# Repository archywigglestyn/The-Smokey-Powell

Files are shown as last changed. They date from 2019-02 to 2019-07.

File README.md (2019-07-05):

# The-Smokey-Powell
The Particle Photon Wifi Blynk controlled BBQ Smoker controller

This controller reads temperature through a thermistor. Control of your smokers heat is made through a fan or
Solid State relay. It has three extra probe inputs to be used as meat probes.
Wifi is used to connect to the cloud. 

The blynk app is used as the main interface from your phone or mobile device. It is worth noting that all the information runs through the cloud. This means one could be shopping for supplies, while also monitoring ones bbq back at home.

A 4x20 I2c LCD is used as a local display and four buttons as the interface controls.
The local interface is a little clunky. The main interface was intended to be the blynk app.

This controller can use replacement thermistors for Weber iGrill2 grilling thermometer. Or any other thermistor that will work 
with a 10k ohm reference resistor.

For those that use the circuit board I designed. The Outputs are sinking.

Watch The Youtube video for more information.
https://youtu.be/kV1lrQCiiBc

Included are links below or look above in the files.

Version 1.2 Fixes issues with slow internet by using event based communication with blynk compaired to timed.
Also allows smoke percent to be set while in off mode.
Version 1.3, 6-16-19 Renames a variable to an unused name. so that the code will compile.

1.4, 7-4-19 A fellow creator found a variable I forgot to change.
https://go.particle.io/shared_apps/5d1ea377e9731c0017650d83

The Blynk App (Look Above) Download Blynk. In Blynk there is an option take a picture of the QR code.

The circuit board gerber file	(Look Above)  Send this Zip file in to order a board. Board dimensions are 4.75"x2.5"
I may also decide to sell them	 3-29-18 I uploaded V1.1, It has a few minor fixes.

where I have my circuit boards made http://www.pcbunlimited.com/ They are great quality and cheap!
Look for Panel Share. It moves around on the website but it's the cheapest way if you only want one. $19.95 as of 3/15/19

schematic of circuit board	SCH,PDF, and BRD (Look Above)

thingiverse link to make 3d printed cases and DIN mounts https://www.thingiverse.com/thing:3453571

Smokey Powell shopping list:

Bill of Material (Look Above)
digikey (some items are optional) you can use screw terminals or barrel jacks for power, outputs and inputs. Really you can use anything you like that matches the pitch. You could even solder wires directly.
(I have not tested all of the parts on this list yet.)

meat probes, https://www.amazon.com/Weber-iGrill-Pro-Meat-Probe/dp/B01M8LG8U5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

2n2222a or 2n2222 these are cheap and appear to be everywhere except Digikey. Looks like they are becoming obsolete. You will need three of them.	
https://www.amazon.com/2N2222-Plastic-Encapsulate-Power-Transistors-600mA/dp/B06XPWS52G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

This is the particle photon. The brains of the operation.
https://www.amazon.com/Particle-Reprogrammable-Development-Prototyping-Electronics/dp/B016YNU1A0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

Optional items:

5vdc buzzer 12mm use this if you want a microwave like beep for the alarm. Otherwise attach whatever you want to the relay, noise maker, light, spinning flag motor.
	https://www.amazon.com/gp/product/B00B0Q4KKO/ref=oh_aui_detailpage_o02_s00?ie=UTF8&psc=1

SS Relay	these work good if you are going to do some high power electric smoking
	https://www.amazon.com/gp/product/B0087ZTN08/ref=oh_aui_search_detailpage?ie=UTF8&psc=1

Antenna
Add an Antenna for extra range. Be sure to switch the text to external in the program.
	https://www.amazon.com/gp/product/B01GMBUS8O/ref=oh_aui_detailpage_o01_s00?ie=UTF8&psc=1

bbq guru Fan	
If you want to use a fan. This is an option. although it does not like pwm so you need to set the pulse range threshold to 100. Otherwise many 12vdc pc fans work well at about 30%
https://www.bbqguru.com/storenav?CategoryId=2&ProductId=44

The connectors I used for the screen
https://www.amazon.com/Hilitchi-JST-XHP-housing-Connector-Adapter/dp/B015Y6JOUG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

Dayton 3FRG5 DC Blower, 12 VDC, 57 CFM. This is a Big blower. The screen dims on my controller when it starts. works well with PWM.
https://www.amazon.com/gp/product/B004KFI6HK/ref=ppx_yo_dt_b_asin_title_o00_s00?ie=UTF8&psc=1

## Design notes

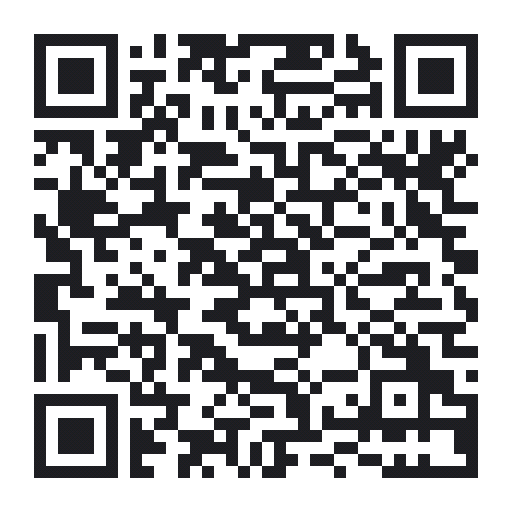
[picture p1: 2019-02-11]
Blynk App.png

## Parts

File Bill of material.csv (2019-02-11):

Manufacturer Part Number | Manufacturer | Digi-Key Part Number | Quantity | Unit Price | Extended Price | Description
MJ1-2503A | CUI Inc. | CP1-2503AM-ND | 4 | 0.71000 | $2.84 | CONN JACK MONO 2.5MM R/A
UFW1E470MDD1TD | Nichicon | 493-10997-1-ND | 2 | 0.24000 | $0.48 | CAP ALUM 47UF 20% 25V RADIAL
CF14JT100R | Stackpole Electronics Inc. | CF14JT100RCT-ND | 2 | 0.10000 | $0.20 | RES 100 OHM 1/4W 5% AXIAL
CF14JT220R | Stackpole Electronics Inc. | CF14JT220RCT-ND | 2 | 0.10000 | $0.20 | RES 220 OHM 1/4W 5% AXIAL
CF14JT470R | Stackpole Electronics Inc. | CF14JT470RCT-ND | 3 | 0.10000 | $0.30 | RES 470 OHM 1/4W 5% AXIAL
CF14JT680R | Stackpole Electronics Inc. | CF14JT680RCT-ND | 3 | 0.10000 | $0.30 | RES 680 OHM 1/4W 5% AXIAL
CF14JT4K70 | Stackpole Electronics Inc. | CF14JT4K70CT-ND | 2 | 0.10000 | $0.20 | RES 4.7K OHM 1/4W 5% AXIAL
LTV-817 | Lite-On Inc. | 160-1366-5-ND | 2 | 0.41000 | $0.82 | OPTOISOLATR 5KV TRANSISTOR 4-DIP
FQP30N06 | ON Semiconductor | FQP30N06FS-ND | 2 | 1.43000 | $2.86 | MOSFET N-CH 60V 30A TO-220
1N5819-E3/54 | Vishay Semiconductor Diodes Division | 1N5819-E3/54GICT-ND | 3 | 0.49000 | $1.47 | DIODE SCHOTTKY 40V 1A DO204AL
1825910-6 | TE Connectivity ALCOSWITCH Switches | 450-1650-ND | 4 | 0.11000 | $0.44 | SWITCH TACTILE SPST-NO 0.05A 24V
G5V-1-2 DC5 | Omron Electronics Inc-EMC Div | Z3824-ND | 1 | 2.34000 | $2.34 | RELAY GEN PURPOSE SPDT 1A 5VDC
EJ508A | MPD (Memory Protection Devices) | EJ508A-ND | 4 | 1.18000 | $4.72 | CONN PWR JACK 2.1X5.5MM SOLDER
C503B-RCN-CW0Z0AA1 | Cree Inc. | C503B-RCN-CW0Z0AA1-ND | 1 | 0.15000 | $0.15 | LED RED CLEAR 5MM ROUND T/H
C503B-GCS-CY0C0791 | Cree Inc. | C503B-GCS-CY0C0791-ND | 1 | 0.25000 | $0.25 | LED GREEN CLEAR 5MM ROUND T/H
C503B-BCN-CV0Z0461 | Cree Inc. | C503B-BCN-CV0Z0461-ND | 1 | 0.21000 | $0.21 | LED BLUE CLEAR 5MM ROUND T/H
L7805CV | STMicroelectronics | 497-1443-5-ND | 1 | 0.52000 | $0.52 | IC REG LINEAR 5V 1.5A TO220AB
507302B00000G | Aavid, Thermal Division of Boyd Corporation | HS115-ND | 1 | 0.41000 | $0.41 | HEATSINK TO-220 2.5W LOW PROFILE
4880G | Aavid, Thermal Division of Boyd Corporation | HS417-ND | 1 | 2.64000 | $2.64 | MOUNTING KIT TO-220
TR2A | Switchcraft Inc. | SC1514-ND | 1 | 3.42000 | $3.42 | CONN JACK MONO 2.46MM PNL MNT
PPTC121LFBN-RC | Sullins Connector Solutions | S6100-ND | 2 | 0.78000 | $1.56 | CONN HDR 12POS 0.1 TIN PCB
OSTVN04A150 | On Shore Technology Inc. | ED10563-ND | 4 | 1.43000 | $5.72 | TERM BLK 4P SIDE ENT 2.54MM PCB
OSTVN02A150 | On Shore Technology Inc. | ED10561-ND | 1 | 0.94000 | $0.94 | TERM BLK 2P SIDE ENT 2.54MM PCB
OSTVN05A150 | On Shore Technology Inc. | ED10564-ND | 1 | 1.80000 | $1.80 | TERM BLK 5P SIDE ENT 2.54MM PCB
ED500/2DS | On Shore Technology Inc. | ED1623-ND | 1 | 0.98000 | $0.98 | TERM BLK 2POS SIDE ENTRY 5MM PCB
OSTTC030162 | On Shore Technology Inc. | ED2601-ND | 1 | 0.95000 | $0.95 | TERM BLK 3POS SIDE ENTRY 5MM PCB
CF14JT10K0 | Stackpole Electronics Inc. | CF14JT10K0CT-ND | 6 | 0.10000 | $0.60 | RES 10K OHM 1/4W 5% AXIAL
SR205E104MAR | AVX Corporation | 478-3192-ND | 6 | 0.22000 | $1.32 | CAP CER 0.1UF 50V Z5U RADIAL

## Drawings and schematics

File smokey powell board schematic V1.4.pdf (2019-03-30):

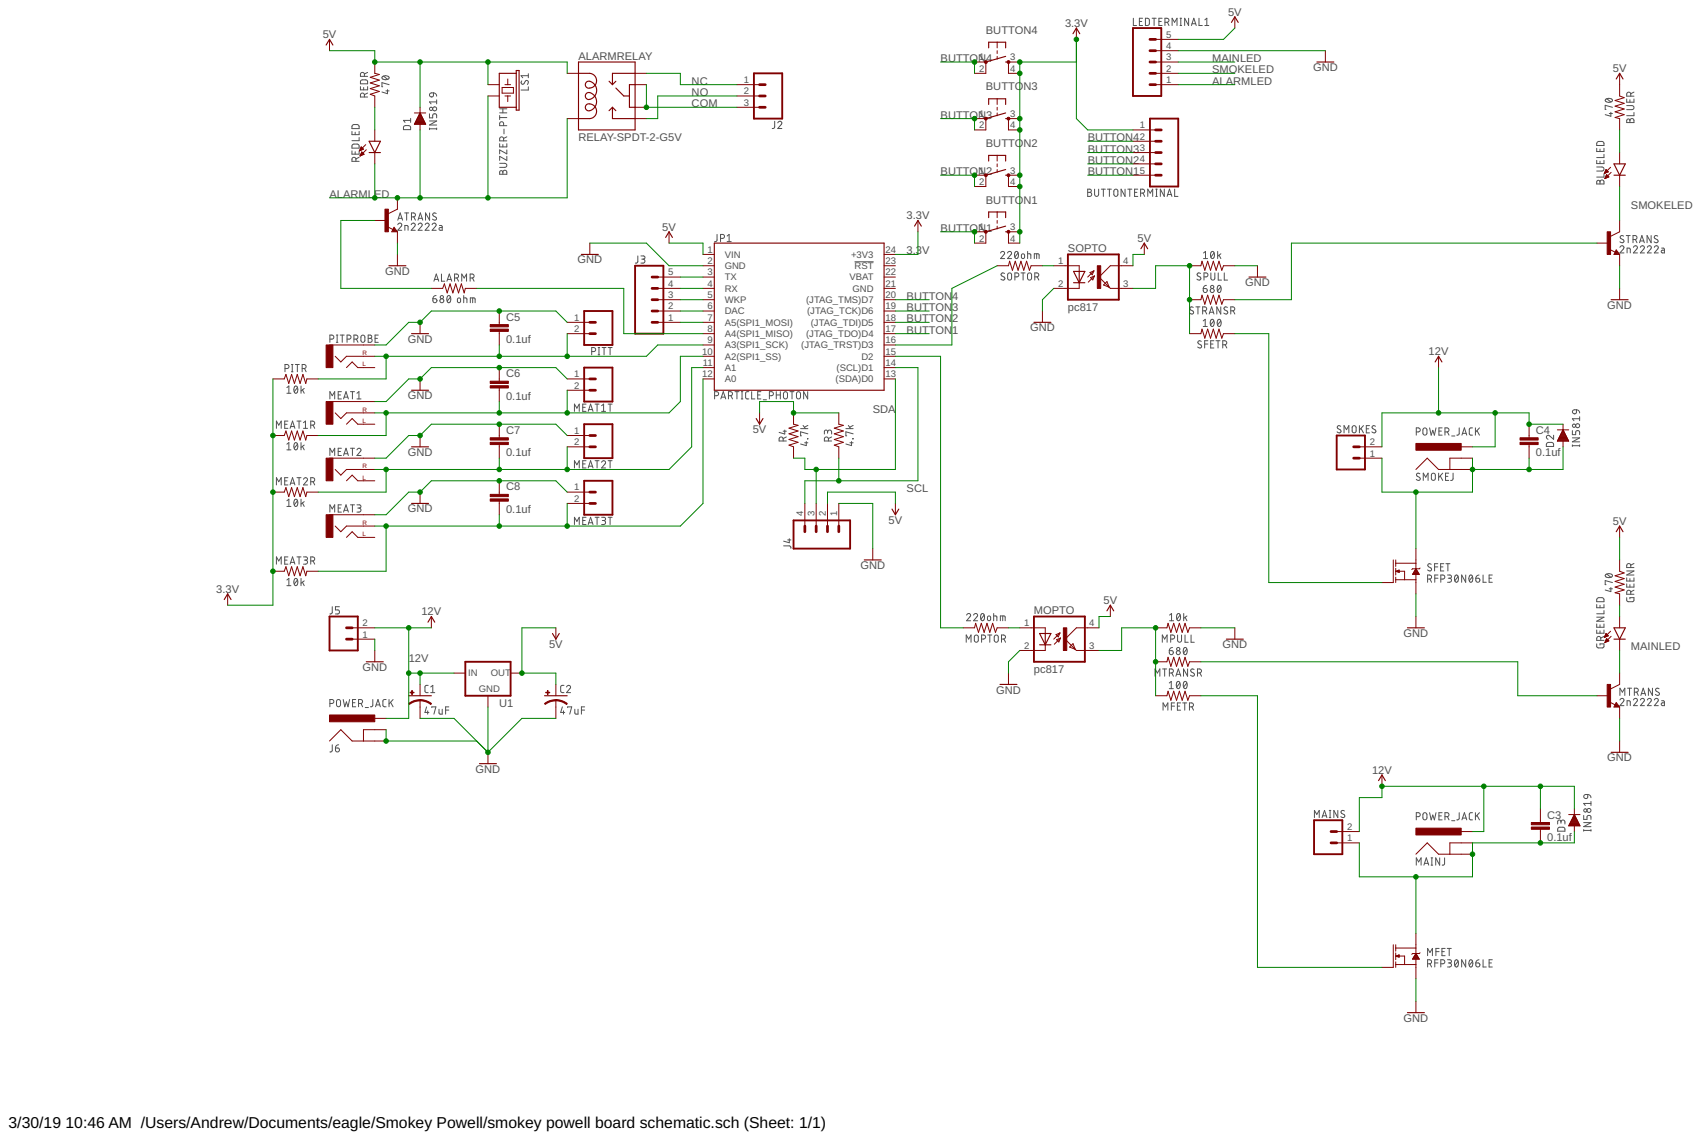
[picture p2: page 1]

3/30/19 10:46 AM /Users/Andrew/Documents/eagle/Smokey Powell/smokey powell board schematic.sch (Sheet: 1/1)

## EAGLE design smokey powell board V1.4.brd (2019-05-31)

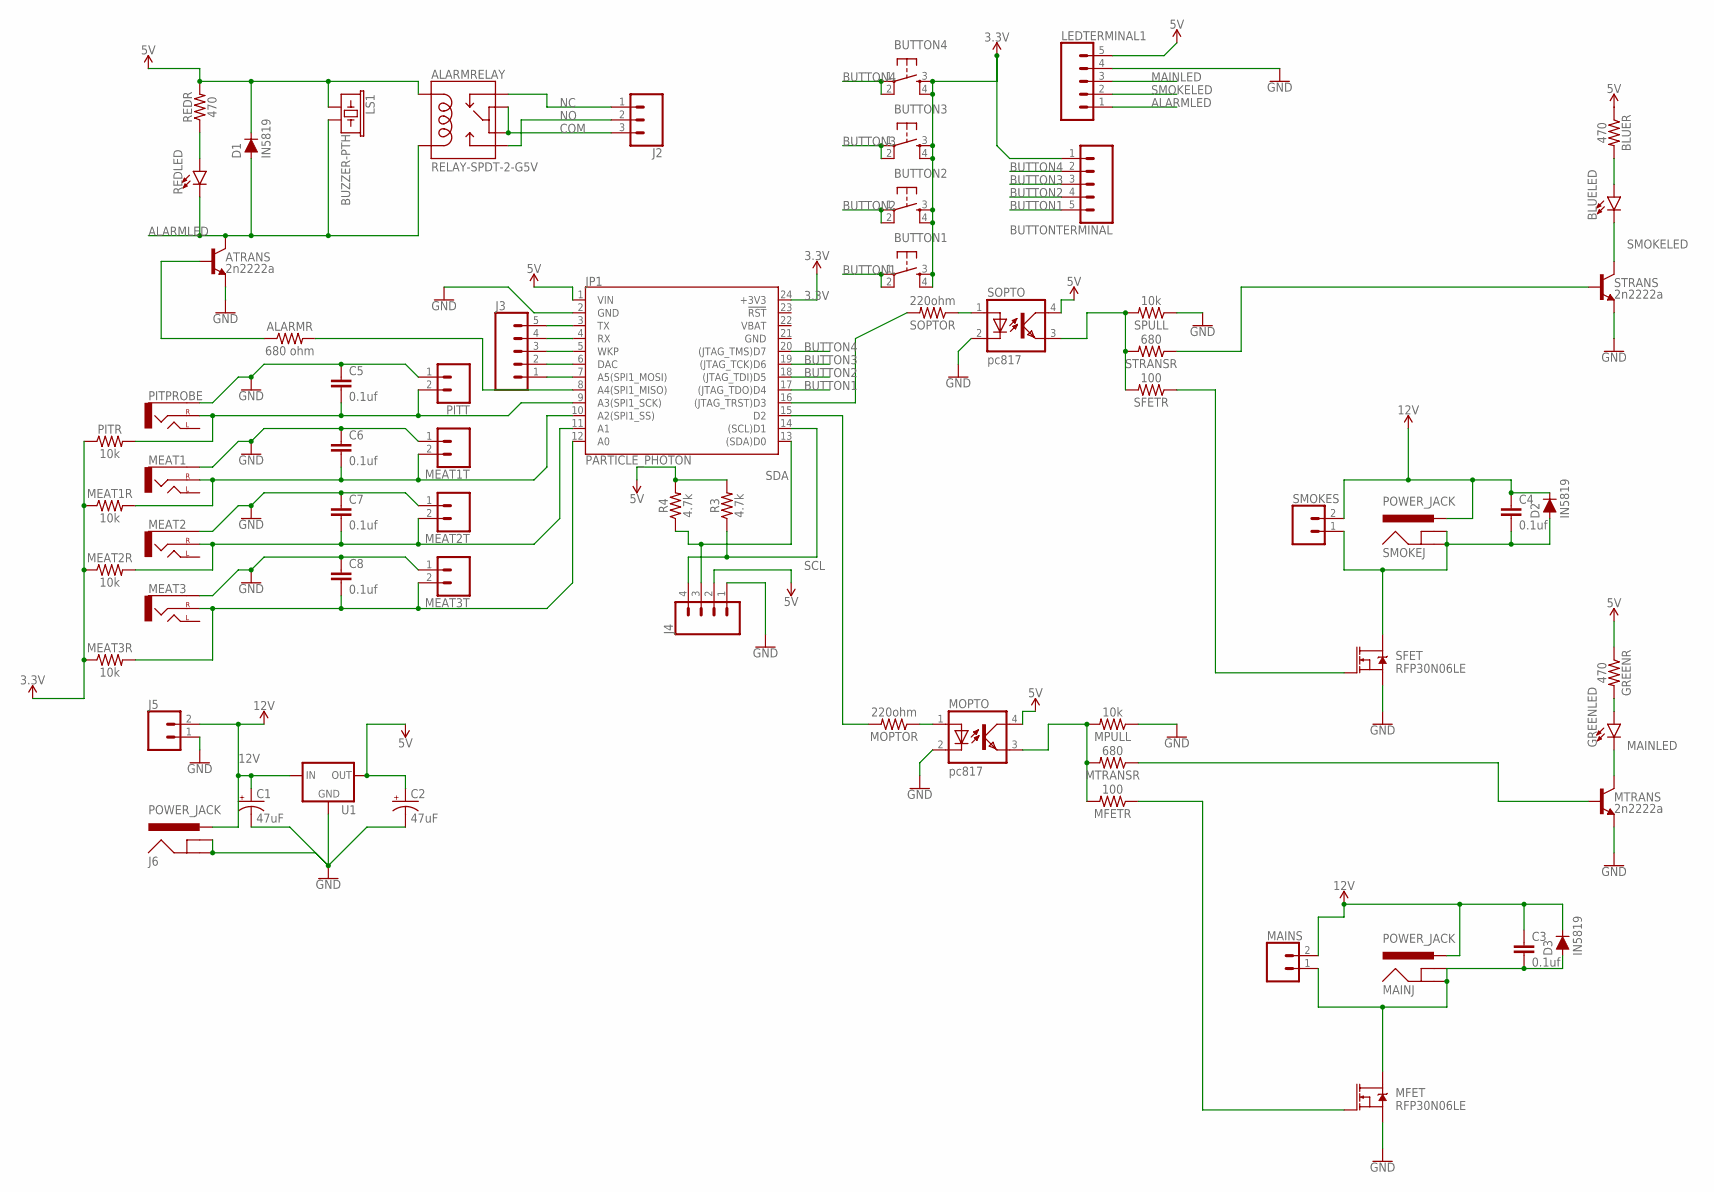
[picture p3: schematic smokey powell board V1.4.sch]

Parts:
ALARMR: 680 ohm; AXIAL-0.3
ALARMRELAY: RELAY-SPDT-2-G5V; RELAY-G5V
ATRANS: 2n2222a; TO-92
BLUELED: LED5MM; LED_5MM
BLUER: 470; AXIAL-0.3
BUTTON1, BUTTON2, BUTTON3, BUTTON4: TAC_SWITCHPTH; TACTILE-PTH
BUTTONTERMINAL: CONN_05PTH_LONGPADS; 1X05_LONGPADS
C1, C2: 47uF; CPOL-RADIAL-2.5MM-6.5MM
C3, C4, C5, C6, C7, C8: 0.1uf; C2.5-2
D1, D2, D3: IN5819; DIODE-1N4001
GREENLED: LED5MM; LED_5MM
GREENR: 470; AXIAL-0.3
J2: CONN_03-SCREW-5MM; SCREWTERMINAL-5MM-3
J3: CONN_05; 1X05
J4: CONN_04LONGPADS; 1X04_LONGPADS
J5: CONN_025MM; SCREWTERMINAL-5MM-2
J6: POWER_JACK; POWER_JACK_PTH
JP1: PARTICLE_PHOTON
LEDTERMINAL1: CONN_05PTH_LONGPADS; 1X05_LONGPADS
LS1: BUZZER-PTH; BUZZER-12MM
MAINJ: POWER_JACK; POWER_JACK_PTH
MAINS: CONN_025MM; SCREWTERMINAL-5MM-2
MEAT1, MEAT2, MEAT3: AUDIO_JACK_2.5MM_2.5MM; STEREOJACK2.5MM_STEREOJACK2.5MM
MEAT1R, MEAT2R, MEAT3R: 10k; AXIAL-0.3
MEAT1T, MEAT2T, MEAT3T: CONN_02PTH3; 1X02_LONGPADS
MFET: RFP30N06LE; TO220V
MFETR: 100; AXIAL-0.3
MOPTO: pc817; DIP4
MOPTOR: 220ohm; AXIAL-0.3
MPULL: 10k; AXIAL-0.3
MTRANS: 2n2222a; TO-92
MTRANSR: 680; AXIAL-0.3
PITPROBE: AUDIO_JACK_2.5MM_2.5MM; STEREOJACK2.5MM_STEREOJACK2.5MM
PITR: 10k; AXIAL-0.3
PITT: CONN_02PTH3; 1X02_LONGPADS
R3, R4: 4.7k; AXIAL-0.3
REDLED: LED5MM; LED_5MM
REDR: 470; AXIAL-0.3
SFET: RFP30N06LE; TO220V
SFETR: 100; AXIAL-0.3
SMOKEJ: POWER_JACK; POWER_JACK_PTH
SMOKES: CONN_025MM; SCREWTERMINAL-5MM-2
SOPTO: pc817; DIP4
SOPTOR: 220ohm; AXIAL-0.3
SPULL: 10k; AXIAL-0.3
STRANS: 2n2222a; TO-92
STRANSR: 680; AXIAL-0.3
U1: V_REG_78XXSINK; TO220-IGO

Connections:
3.3V: BUTTON1.3, BUTTON1.4, BUTTON2.3, BUTTON2.4, BUTTON3.3, BUTTON3.4, BUTTON4.3, BUTTON4.4, BUTTONTERMINAL.1, JP1.24 (+3V3), MEAT1R.P$1 (1), MEAT2R.P$1 (1), MEAT3R.P$1 (1), PITR.P$1 (1)
5V: ALARMRELAY.2, BLUER.P$1 (1), C2.1 (+), D1.C, GREENR.P$1 (1), J4.2, JP1.1 (VIN), LEDTERMINAL1.5, LS1.+ (1), MOPTO.4 (COL), R3.P$2 (2), R4.P$2 (2), REDR.P$2 (2), SOPTO.4 (COL), U1.OUT
12V: C1.1 (+), C3.1, C4.1, D2.C, D3.C, J5.2, J6.PWR, MAINJ.PWR, MAINS.2, SMOKEJ.PWR, SMOKES.2, U1.IN
ALARMLED: ALARMRELAY.9, ATRANS.1 (C), D1.A, LEDTERMINAL1.1, LS1.- (2), REDLED.K (C)
BUTTON1: BUTTON1.1, BUTTON1.2, BUTTONTERMINAL.5, JP1.17 ((JTAG_TDO)D4)
BUTTON2: BUTTON2.1, BUTTON2.2, BUTTONTERMINAL.4, JP1.18 ((JTAG_TDI)D5)
BUTTON3: BUTTON3.1, BUTTON3.2, BUTTONTERMINAL.3, JP1.19 ((JTAG_TCK)D6)
BUTTON4: BUTTON4.1, BUTTON4.2, BUTTONTERMINAL.2, JP1.20 ((JTAG_TMS)D7)
COM: ALARMRELAY.5, ALARMRELAY.6, J2.3
GND: ATRANS.3 (E), C1.2 (-), C2.2 (-), C5.1, C6.1, C7.1, C8.1, J4.1, J5.1, J6.GND, J6.GNDBREAK, JP1.2 (GND), JP1.21 (GND), LEDTERMINAL1.4, MEAT1.RING1 (SLEEVE), MEAT1T.1, MEAT2.RING1 (SLEEVE), MEAT2T.1, MEAT3.RING1 (SLEEVE), MEAT3T.1, MFET.3 (S), MOPTO.2 (C), MPULL.P$1 (1), MTRANS.3 (E), PITPROBE.RING1 (SLEEVE), PITT.1, SFET.3 (S), SOPTO.2 (C), SPULL.P$1 (1), STRANS.3 (E), U1.GND
MAINLED: GREENLED.K (C), LEDTERMINAL1.3, MTRANS.1 (C)
unnamed: C7.2, JP1.11 (A1), MEAT2.TIP (RIGHT), MEAT2R.P$2 (2), MEAT2T.2
unnamed: ALARMR.P$2 (2), JP1.8 (A4(SPI1_MISO))
unnamed: MTRANS.2 (B), MTRANSR.P$1 (1)
unnamed: ALARMR.P$1 (1), ATRANS.2 (B)
unnamed: STRANS.2 (B), STRANSR.P$1 (1)
unnamed: J3.5, JP1.3 (TX)
unnamed: J3.4, JP1.4 (RX)
unnamed: J3.3, JP1.5 (WKP)
unnamed: J3.2, JP1.6 (DAC)
unnamed: J3.1, JP1.7 (A5(SPI1_MOSI))
unnamed: MFET.1 (G), MFETR.P$1 (1)
unnamed: C3.2, D3.A, MAINJ.GND, MAINJ.GNDBREAK, MAINS.1, MFET.2 (D)
unnamed: JP1.16 ((JTAG_TRST)D3), SOPTOR.P$2 (2)
unnamed: JP1.15 (D2), MOPTOR.P$2 (2)
unnamed: SOPTO.1 (A), SOPTOR.P$1 (1)
unnamed: MOPTO.1 (A), MOPTOR.P$1 (1)
unnamed: MFETR.P$2 (2), MOPTO.3 (EMIT), MPULL.P$2 (2), MTRANSR.P$2 (2)
unnamed: SFETR.P$2 (2), SOPTO.3 (EMIT), SPULL.P$2 (2), STRANSR.P$2 (2)
unnamed: SFET.1 (G), SFETR.P$1 (1)
unnamed: REDLED.A, REDR.P$1 (1)
unnamed: C4.2, D2.A, SFET.2 (D), SMOKEJ.GND, SMOKEJ.GNDBREAK, SMOKES.1
unnamed: BLUELED.A, BLUER.P$2 (2)
unnamed: GREENLED.A, GREENR.P$2 (2)
unnamed: C8.2, JP1.12 (A0), MEAT3.TIP (RIGHT), MEAT3R.P$2 (2), MEAT3T.2
unnamed: C6.2, JP1.10 (A2(SPI1_SS)), MEAT1.TIP (RIGHT), MEAT1R.P$2 (2), MEAT1T.2
unnamed: C5.2, JP1.9 (A3(SPI1_SCK)), PITPROBE.TIP (RIGHT), PITR.P$2 (2), PITT.2
NC: ALARMRELAY.1, J2.1
NO: ALARMRELAY.10, J2.2
SCL: J4.4, JP1.14 ((SCL)D1), R3.P$1 (1)
SDA: J4.3, JP1.13 ((SDA)D0), R4.P$1 (1)
SMOKELED: BLUELED.K (C), LEDTERMINAL1.2, STRANS.1 (C)
VBAT: JP1.22 (VBAT)

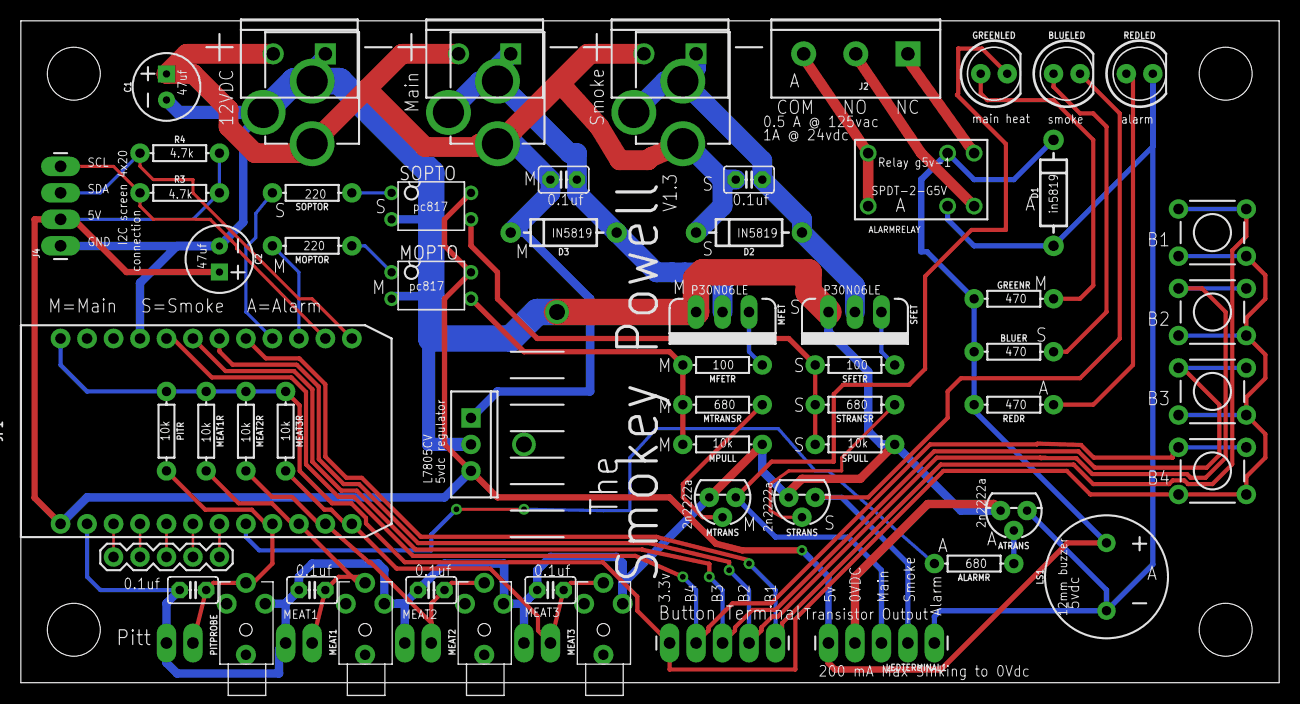
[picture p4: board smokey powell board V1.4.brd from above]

Board: 2 copper layers, 120.7 x 63.5 mm, 66 parts (0 on the bottom side), 42 nets.

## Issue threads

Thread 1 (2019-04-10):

100k thermistor probes

philgood, 2019-04-10:
Would it be difficult to incorporate 100K thermistor temperature probes?

archywigglestyn, 2019-04-10:
It should work. My first ones were 100k, I was using 100k series resistors.
I found that when approaching high temps the resistance would drop very low
and give a poor signal resolution. When compairing to the 100k series
resistor. So keep in mind if your readings are speratic you may need to
better match your series resistor. Software wise, piece of cake, just enter
the values of you hardware.

Andrew

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

philgood, 2019-04-10:
Great to know, thanks for the info. I'm going to make a build, will post in my results for your info. Ryan

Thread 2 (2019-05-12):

Board resistor value

blaster452, 2019-05-12:
Notice the pcb layout has the MPULL and SPULL resistors shown as 100K while the schematic and BOM show the value as 10K. Not a big issue but though I would mention it. Otherwise the board design is very good.

archywigglestyn, 2019-05-12:
Thanks for letting me know. There were some changes throughout the process,
must have missed it.

Appreciate it

Andrew

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

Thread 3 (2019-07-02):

Alarm Problem

NaServas, 2019-07-02:
Hey,

unfurtonately the Alarm doesn't work on my Hardware.
The Hardware is not the problem (I set Pin A4 manually high => LED was on+sound signal)

When pressing the Verify Button in the app, I get the Signal LED in the app. But the alarm on the PCB Hardware doesn't go off.

I also tried to figure out what is the problem, but i wasn't able to bring it to work.
Maybe it has something to do with the two variables "Alarm" and "alarm", which both exist in the code.

archywigglestyn, 2019-07-02:
Hey thanks for finding that. I had a problem with the word alarm. It looked
like particle decided to use it for them selves so then it ran into a bunch
of compile errors.

The way I fixed it was to just make it Alarm instead of alarm.

If you change all of the alarm (s) to Alarm it should be back to normal.

Sorry for the trouble.

If you could please give me the line numbers that have alarm, to aid in
fixing it. That would be great

Andrew

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

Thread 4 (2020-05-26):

2.5mm socket eagle model

NaServas, 2020-05-26:
Hello,

take care, which probes you use!
If you use probes with grounded shield, they get shortcut.

If you take a look on the datasheet of the 2.5mm, Pin 1 connects to the shield of the cable.
In the EAGLE schematics file the connection is OK, but the EAGLE Model of the 2.5mm socket is wrong.
Instead of putting the shield to ground, it connects the shields to the Analog Input of the Particle Photon.

Datasheet of 2.5mm socket: https://www.cuidevices.com/product/resource/mj1-2503a.pdf

Using probes with grounded shields leads to cutting all Meat Probe Inputs short.
=> You measure all 4 probes with every Analog Input Pit to Meat 3.

There are 2 solutions:

1.) Using probes without grounded shields
2.) Change model of the 2.5mm sockets in the EAGLE file according to the Datasheet.

As I think the probes used from Archy don't have grounded shields, it the current design is perfectly fine. Problems only occure with probes with grounded shields.

I hope I was able to explain the problem.

Sebastian

NaServas, 2020-05-27:
Alternatively you could try, if this already fits in the current PCB Layout:

https://www.digikey.at/product-detail/de/schurter-inc/4831-2230/4831-2230-ND/2646625

But I think the best solution would be to use the right Model in the EAGLE files und stick with the MJ1-2503A  connector

archywigglestyn, 2020-05-27:
Sebastian,

Thanks for finding the mistake and helping with the solution. I'll be sure
to look into it.

Andrew

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

NaServas, 2020-05-28:
As I anyways updated the PCB Layout, I share it here.
But I don't know if the 2.5mm sockets still perfectly fit into the holes in the case.
The eagle files should work after you import the MJ1-2503A Models to eagle.

A Layout Check with the design rules from JCB Layout was fine.

[smokey powell board V1.5.zip](https://github.com/archywigglestyn/The-Smokey-Powell/files/4694256/smokey.powell.board.V1.5.zip)

Sebastian

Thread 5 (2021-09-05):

Port to ESP32

Bananamannn, 2021-09-05:
Hi All,

I'm not much of a programmer but I was wondering if anyone knew how much work would be involved in porting this from a Particle Photon to an ESP32 dev board based system?

This would allow you to have a webpage running locally on the ESP32 that you could connect too and not have to rely on the Blynk app or the Particle Cloud

archywigglestyn, 2021-09-06:
Hello Bananaman,

Although it may not look like it, I myself don't know a whole lot of
programming. This sounds like a great idea.
I have studied using an Arduino as a web server for a different project. I
don't think it would be too hard, all the data is pretty simple. It would
be time consuming switching out all of the blynk communication code for
server data.
It could definitely be done. I'm just not exactly sure how much time
would be involved.

 It actually sounds great to have it host the data to get around using
blynk. Initially with the project, a big barrier was the phone app. I
didn't have enough interest to learn how to create my own app.
I never actually thought of using a simple webpage to host the interface.

Thanks,
Andrew

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

Bananamannn, 2021-09-06:
Hi Andrew,

That was a very quick response. Well based off this I think you know more about programming than I do. I've used a couple of other systems that are controlled via a simple webserver on an ESP8266 (links below) and it works quite well. You might be able to copy some segments of their code to make it easier?

With the newer ESP32 you'll get bluetooth as well.

[https://github.com/vitotai/BrewPiLess](https://github.com/vitotai/BrewPiLess)
[https://github.com/universam1/iSpindel](https://github.com/universam1/iSpindel)

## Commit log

2018-07-08 Add files via upload
    This is the parts list for the circuit board
    [Bom_7571589.csv]
2018-07-08 gerber files for making a circuit board
    Send this Zip in and order a board Board dimensions are 4.5"x2.5"
2018-07-08 Circuit board schematic
2018-07-08 Bill Of Meterial
    Not everything on this list is needed. The board can accept barrel jacks and screw terminals for example.
    [Bom_7571589.csv]
2018-07-23 Circuit board gerber file
    Send this file in to have a circuit board made. It cost me under $20 to make one
2019-02-11 Rename Smokey Powell BOM.csv to Bill of material
2019-03-30 Add files via upload
    Send this file in to have a board fabricated.
2019-03-30 Add files via upload
    Gerber Files for ordering a circuit board. V1.3 Added a 5v pin to the transistor area for powering the unit externally from a 5vdc power supply.

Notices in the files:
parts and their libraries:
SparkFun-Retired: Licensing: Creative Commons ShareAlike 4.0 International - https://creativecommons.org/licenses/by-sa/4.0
